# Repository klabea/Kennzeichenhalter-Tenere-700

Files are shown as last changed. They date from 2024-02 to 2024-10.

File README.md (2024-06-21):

# Erweiterung Kennzeichenhalter Tenere 700
Grundlage ist der KEDO-T7-Kennzeichenhalter. Die Basis des Halters wird mit Aufnahmen versehen, an denen die originalen Blinker (MJ 2023, LED) befestigt werden können.
Von den Haltern gehen Stege aus damit die Lücke zwischen Rücklicht und Träger ausgefüllt wird.

Der unten offene Bereich mit den freiliegende Kabeln wird mit einer zusätzlichen Abdeckung geschlossen und sorgt für einen effektiven Spritzschutz.

Die Teile wurden auf einem Prusa MK3 gedruckt. Zum befestigen des Spritzschutzes sind in den Blinkeraufnahmen M4 Inserts eingelassen.

Abstand der Blinker zueinander ca. 215 mm (Innenmaß).

Zusätzliches Befestigungsmaterial:

|Anzahl|Bezeichnung |Maße |DIN/EN  |
|:---: | --- | --- | --- |
|2 |Zylinderschraube mit Innensechskant|M6 x 25  |ISO 4762|
|2 |Zylinderschraube mit Innensechskant|M4 x 12  |ISO 4762|
|4 |Zylinderschraube mit Innensechskant|M3 x 10  |ISO 4762|
|2 |M6 Karrosseriescheibe |ø18 x 1,5| | 
|2 |M4 Karrosseriescheibe |ø12 x 1  | |  
|2 |Gewindeeinsatz |M4 | |

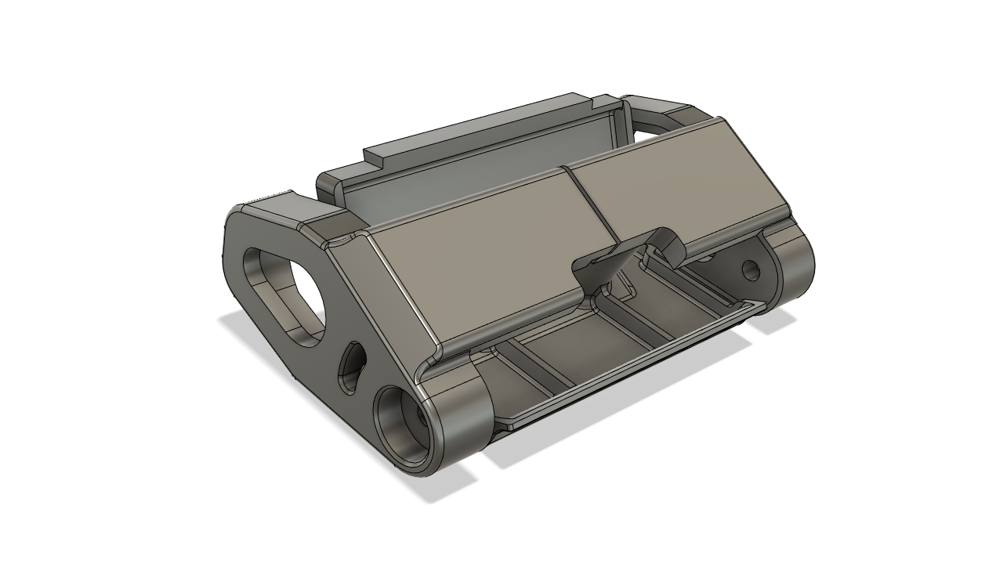
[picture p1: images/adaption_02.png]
Adaption


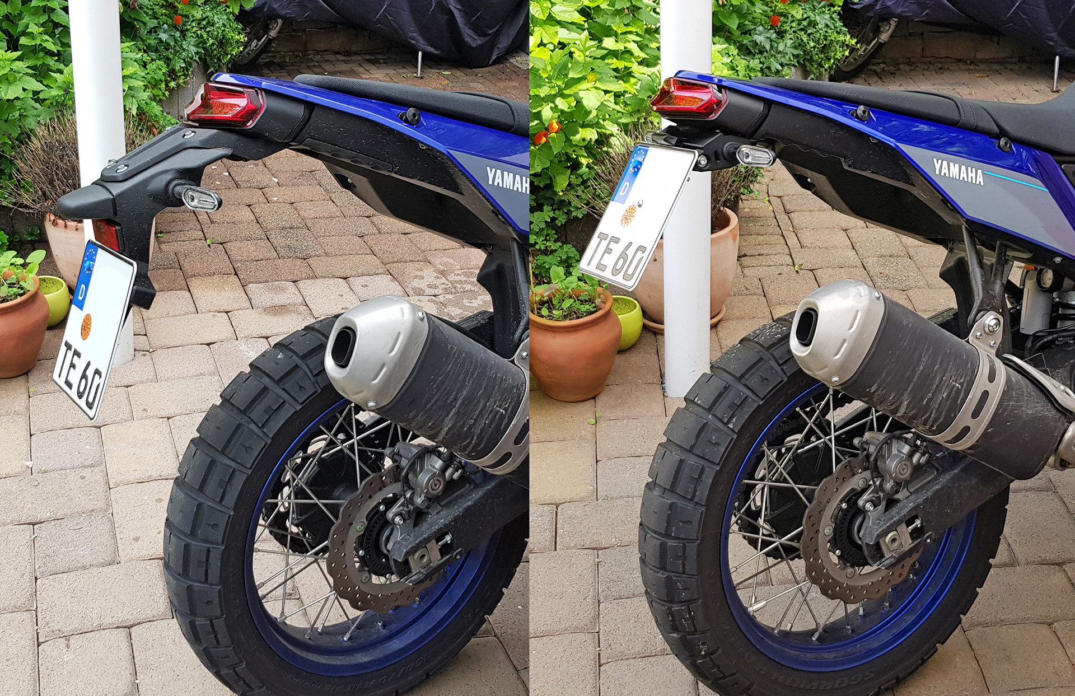
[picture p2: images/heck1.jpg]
vorher-nachher


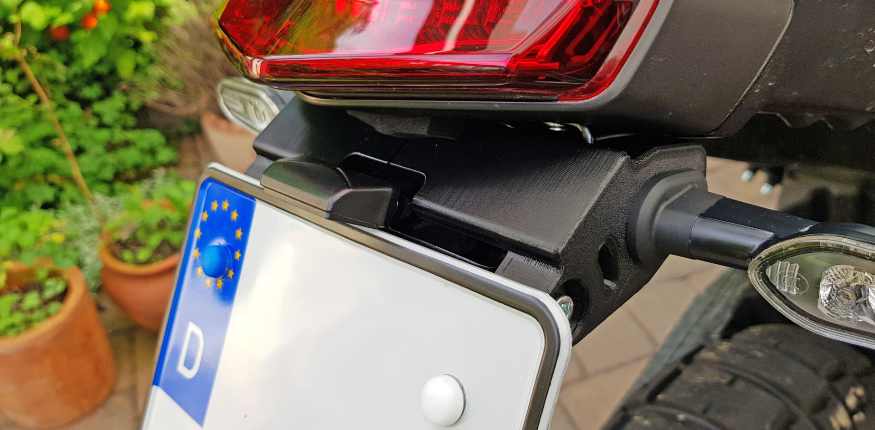
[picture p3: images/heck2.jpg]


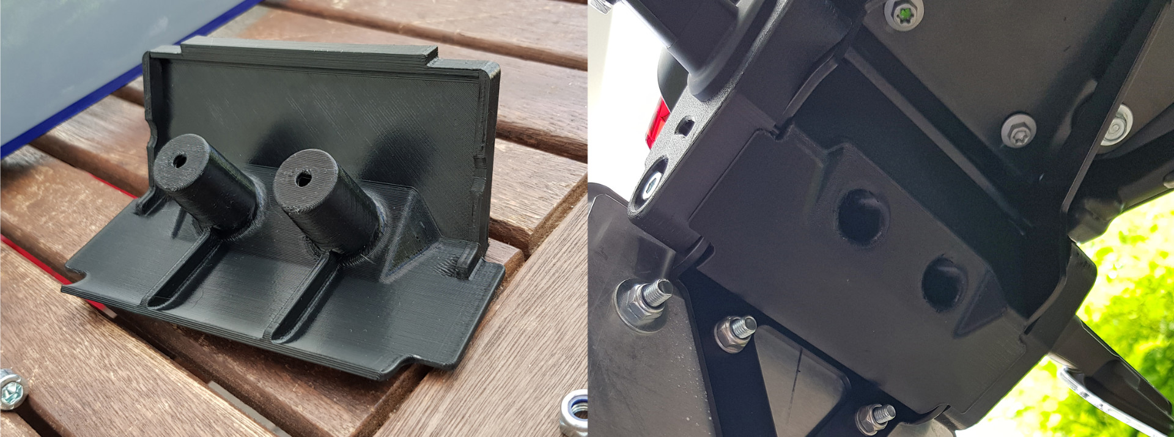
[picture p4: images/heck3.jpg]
Cover


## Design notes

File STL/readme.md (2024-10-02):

## Angaben für PrusaSlicer

**Cover:**
* PETG
* Nozzel 0,4 mm
* Schichthöhe 0,2 mm
* Infill 100%
* Stützen: Stützen nur auf dem Druckbett

**Bracket LH/RH**
* PETG
* Nozzel 0,4 mm
* Schichthöhe 0,2 mm
* Perimeter 3
* Infill 50%
* auf der Achse der M6-Verschraubung Modifizierer, Zylinder ø12 mm, hinzugefügt: Infill 100%
* Stützen: Stützen nur auf dem Druckbett

## UPDATE 2024-02-09
**Cover-02:** Optimierung des Spritzschutzes. Die seitlichen Rippen geschlossen und Kragen zum Kennzeichenhalter verlängert.

## UPDATE 2024-06-21
**Cover-03:** Weitere Optimierung des Spritzschutzes (Abwärtskompatibel).

> [!NOTE]
> **Bracket LH/RH:** Ab der Version 03 kann der Steg gegen Missbrauch (abknicken) über zwei M3x10 Zylinderschrauben abgesichert werden. Verschraubung direkt in den Kunststoff bis zum Anschlag.

**Bracket-03:** Optimierung des Spritzschutzes. Aufnahme M3 hinzu, wg. Absicherung gegen Missbrauch (Abwärtskompatibel).

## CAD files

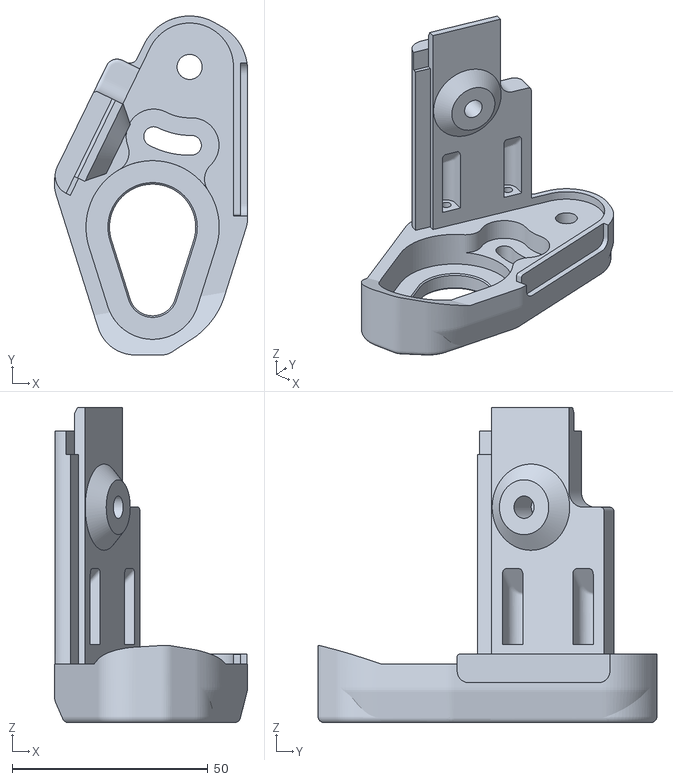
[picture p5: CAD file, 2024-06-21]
STL/bracket-rh-03.stl
49.3 x 86.5 x 80.5

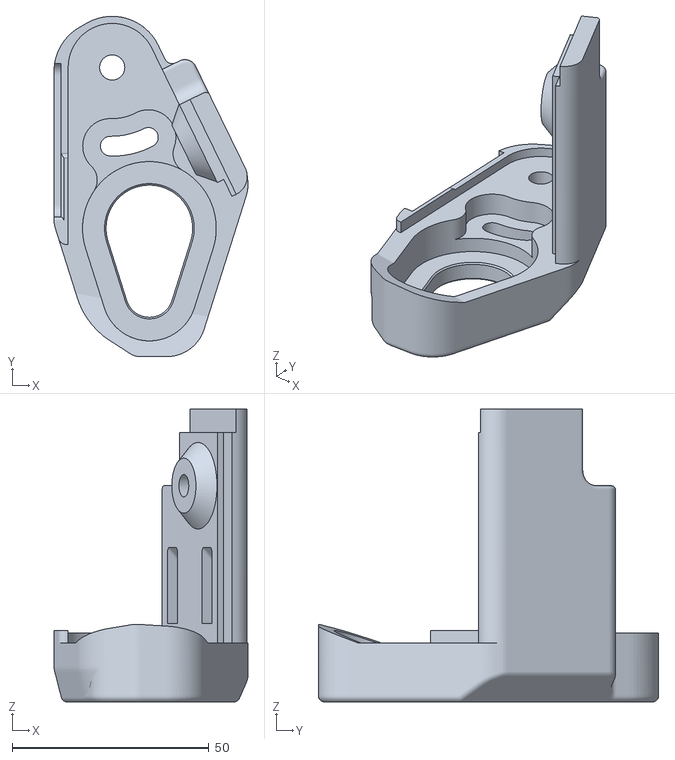
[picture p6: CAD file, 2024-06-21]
STL/bracket-lh-03.stl
49.3 x 86.5 x 74.5

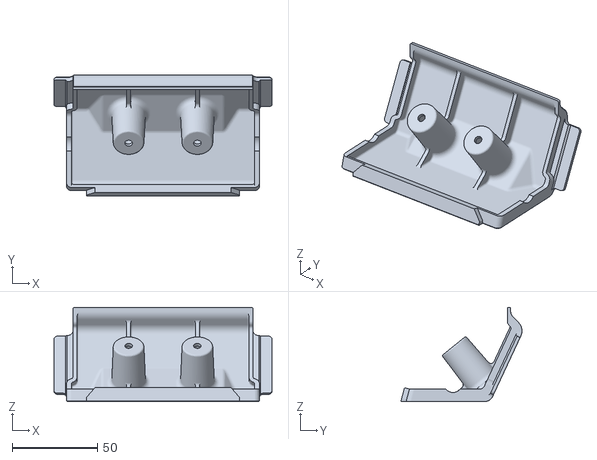
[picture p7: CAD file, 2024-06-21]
STL/cover-03.stl
128.0 x 71.1 x 55.3
